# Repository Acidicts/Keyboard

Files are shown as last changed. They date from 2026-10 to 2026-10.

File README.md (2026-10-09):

# Keyboard
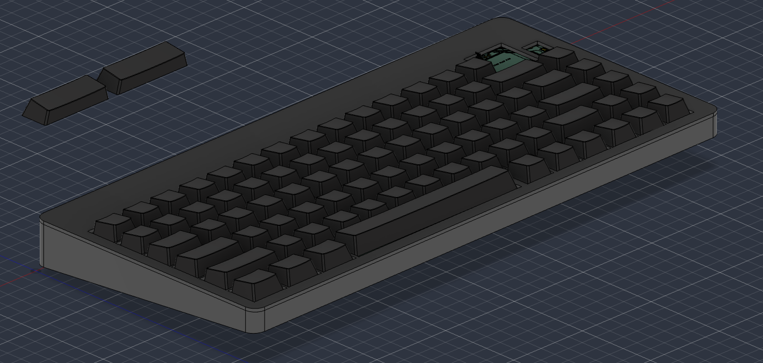
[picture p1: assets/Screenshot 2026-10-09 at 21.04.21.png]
assembly





Sooo, this is a keyboard with a fun little oled display (via i2c) and rotary encoder with some rgb leds, following a modified ansi layout: `"` and `@` are swapped

### Features
- Powered via usb-c
- Wired keyboard
- RP2354A (2MB on onboard memory)
- RGB LEDS

### Models
- [Keyboard Assemble  (f3z)](.Assembly.f3z)
- [Keyboard Case      (step)](./case/Case.step)
- [Keyboard Top Plate (step)](./case/Top-Plate.step)

### Assembly
- The case is a bit bigger than most 3d printers so you may need a 3rd party service for it
- Any ansi keycap set compatible with 75% keyboards should work i have not included price for them as you can make them in many ways,  either buy, 3d print, etc
- feel free to swap the `@` and `"` back if you prefer it that way just edit the [main.py](/firmware/main.py)
1. I recommend using PCBA for the top layer as those parts may be difficult to solder
2. On arrival of your half made pcb, start with soldering on the diodes facing in the direction of the silkscreen diagram
3. After solder on the rgb leds matching the notch up to the silkscreen too
4. Finally solder on your key switches to the board (I didn't want to give anyone the pain of manually soldering hot swaps on)
5. Put on your keycaps to key switches
6. Use a soldering iron to put in a m3 heat insert into the hole in the case
7. Put the pcb in the case
8. use a m3 screw to firmly mount to case but be wary of the underneath components so use spacers for it

### Case
[case](/case/Case.step)
[https://a360.co/476DL3y](https://a360.co/476DL3y)

### Firmware
1. Download the latest release of circuitpython from [here](https://downloads.circuitpython.org/bin/seeeduino_xiao_rp2040/en_GB/adafruit-circuitpython-seeeduino_xiao_rp2040-en_GB-10.3.0.uf2)
2. whilst powering the board (by plugging in usbc) hold down the boot button(labelled as `SW1` and plug it into your computer. The board should show up as a USB drive called `RPI-RP2` or something similar.
3. Drag and drop the downloaded UF2 file onto the `RPI-RP2` drive. The board will reboot and show up as a USB drive called `CIRCUITPY`.
4. drag and drop the contents of the [`firmware`](./firmware) folder onto the `CIRCUITPY` drive.
5. Restart the board and it should now be ready to use.

### BOMs
| Name | Link |
| --- | --- |
| Overview | [here](./BOM.csv) |
| LCSC List (included in addition parts) | [here](./BOMS/LCSC_BOM.csv) |
| PCBA Parts | [here](./BOMS/jlcpcb_pcb_BOM.csv) |

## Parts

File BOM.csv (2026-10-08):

Name | Source | Quantity | Cost | Link
Leobog key switches | Epomaker | 100(84 needed) | $26.99 | https://epomaker.com/products/leobog-reaper-switch-set
PCB | JLCPCB | 5(1 needed) | $29.50 | https://jlcpcb.com
PCBA | JLCPCB | 2(1 needed) | $44.62 | https://jlcpcb.com
PCB Shipping | JLCPCB | 1 | $40.00 | https://jlcpcb.com
NCP1117-3.3_SOT223 | Farnell UK | 1 | $1.11( shipping not included ) | https://uk.farnell.com/onsemi/ncp1117stat3g/ic-voltage-regulator/dp/1703381
LCSC parts list | LCSC | N/A | $17.46 | https://www.lcsc.com

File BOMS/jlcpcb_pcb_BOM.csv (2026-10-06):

\Designator | Per Board Qty | Order Qty | Description | MPN | LCSC Part # | Type | Supplier | Line Price (USD)
C1, C2 | 2 | 4 | 15pF 0603 50V C0G | CL10C150JB8NNNC | C1644 | Basic | JLCPCB | 0.0452
C3, C4, C5 | 3 | 6 | 4.7µF 0603 16V | CL10A475KO8NNNC | C19666 | Basic | JLCPCB | 0.1770
C6, C7 | 2 | 4 | 10µF 0805 25V | CL21A106KAYNNNE | C15850 | Basic | JLCPCB | 0.2604
C10, C11, C12, C13... |  | 24 | 100nF 0603 X7R | CC0603KRX7R9BB104 | C14663 | Basic | JLCPCB | 0.2952
L1 | 1 | 5 | 3.3µH inductor 2016 | AOTA-B201610S3R3-101-T | C42411119 | Extended | JLCPCB | 1.4145
R1, R2 | 2 | 20 | 5.1kΩ 0603 1% | FRC0603F5101TS | C2907044 | Extended | JLCPCB | 0.0440
R3, R5 | 2 | 20 | 27Ω 0805 5% | 0805W8F270JT5E | C17594 | Extended | JLCPCB | 0.0580
R4, R7, R8 | 3 | 20 | 1kΩ 0603 1% | RC0603FR-071KL | C22548 | Extended | JLCPCB | 0.0720
R9 | 1 | 20 | 33Ω 0603 1% | FRC0603F33R0TS | C2909394 | Extended | JLCPCB | 0.0540
SW1, SW2 | 2 | 6 | Push button switch 3x4x2.5mm | HX 3x4x2.5-PA-4N | C55200589 | Extended | JLCPCB | 0.1776
U1 | 1 | 2 | RP2354A microcontroller | RP2354A | C41378174 | Extended | JLCPCB | 2.5524
U2 | 1 | 5 | 12MHz crystal | ABM8-272-T3 | C20625731 | Extended | JLCPCB | 3.0970
USB1 | 1 | 3 | USB Type-C 16-pin connector | TYPE-C 16PIN 2MD(073) | C2765186 | Extended | JLCPCB | 0.2229

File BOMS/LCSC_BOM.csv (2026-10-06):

Name | Product ID | Quantity | Cost | Link
MBR0530 Diode | C5204746 | 90(84 needed) | $2.02 | https://www.lcsc.com/product-detail/C5204746.html
SK6812MINI-E | C5149201 | 90(84 needed) | $5.85 | https://www.lcsc.com/product-detail/C5149201.html
EC11E1834403 | C361165 | 1(1 needed) | $1.98 | https://www.lcsc.com/product-detail/C361165.html
Extra Costs(Shipping handling) | N/A | 1 | $7.61 | https://www.lcsc.com

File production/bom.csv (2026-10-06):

Designator | Footprint | Quantity | Value | LCSC Part #
C1, C2 | 0603 | 2 | 15pF
C10, C11, C12, C13, C14, C15, C16, C17, C18, C43, C8, C9 | 0603 | 12 | 100n
C19, C20, C21, C22, C23, C24, C25, C26, C27, C28, C29, C30, C31, C32, C33, C34, C35, C36, C37, C38, C39, C40, C41, C42, C6, C7 | 0805 | 26 | 10u
C3, C4, C5 | 0603 | 3 | 4.7u
D1, D10, D11, D12, D13, D14, D15, D16, D17, D18, D19, D2, D20, D21, D22, D23, D24, D25, D26, D27, D28, D29, D3, D30, D31, D32, D33, D34, D35, D36, D37, D38, D39, D4, D40, D41, D42, D43, D44, D45, D46, D47, D48, D49, D5, D50, D51, D52, D53, D54, D55, D56, D57, D58, D59, D6, D60, D61, D62, D63, D64, D65, D66, D67, D68, D69, D7, D70, D71, D72, D73, D74, D75, D76, D77, D78, D79, D8, D80, D81, D82, D9 | LED_SK6812MINI-E_3.2x2.8mm_P1.5mm_ReverseMount | 82 | SK6812MINI-E
J1 | SSD1306_OLED_0.96 | 1 | Conn_01x04_Pin
L1 | IND-SMD_L2.0-W1.6_AOTA-B201610S3R3-101-T | 1 | AOTA-B201610S3R3-101-T | C42411119
R1, R2 | R0603 | 2 | FRC0603F5101TS | C2907044
R3, R5 | R0805 | 2 | 0805W8F270JT5E | C17594
R4, R7, R8 | 0603 | 3 | RC0603FR-071KL | C22548
R9 | R0603 | 1 | FRC0603F33R0TS | C2909394
SW1, SW2 | SW-SMD_4P-L4.2-W3.4-P2.15-LS5.2 | 2 | HX 3X4X2.5-PA-4N PUSH BUTTON SWITCH | C55200589
SW10, SW11, SW12, SW13, SW14, SW15, SW17, SW18, SW19, SW20, SW21, SW22, SW23, SW24, SW25, SW26, SW27, SW28, SW29, SW3, SW30, SW32, SW34, SW35, SW36, SW37, SW38, SW39, SW4, SW40, SW41, SW42, SW43, SW44, SW45, SW47, SW49, SW5, SW50, SW51, SW52, SW53, SW54, SW55, SW56, SW57, SW58, SW59, SW6, SW62, SW64, SW65, SW66, SW67, SW68, SW69, SW7, SW70, SW71, SW72, SW73, SW75, SW77, SW8, SW87, SW88, SW89, SW9, SW90, SW91, SW92 | SW_Cherry_MX_1.00u_PCB | 71 | SW_Push
SW16 | RotaryEncoder_Alps_EC11E-Switch_Vertical_H20mm | 1 | RotaryEncoder_Switch
SW31, SW48, SW60 | SW_Cherry_MX_2.00u_PCB | 3 | SW_Push
SW33, SW46 | SW_Cherry_MX_1.50u_PCB | 2 | SW_Push
SW63 | SW_Cherry_MX_2.25u_PCB | 1 | SW_Push
SW74 | SW_Cherry_MX_1.75u_PCB | 1 | SW_Push
SW78 | SW_Cherry_MX_1.25u_PCB | 1 | SW_Push
SW79, SW80 | SW_Cherry_MX_1.25u_Plate | 2 | SW_Push
SW81 | SW_Cherry_MX_6.25u_PCB | 1 | SW_Push
U1 | QFN-60-1EP_7x7mm_P0.4mm_EP3.4x3.4mm | 1 | RP2354A
U10, U11, U12, U13, U14, U15, U16, U17, U19, U20, U21, U22, U23, U24, U25, U26, U27, U28, U29, U30, U31, U32, U33, U34, U35, U36, U37, U38, U39, U4, U40, U41, U42, U43, U44, U45, U46, U47, U48, U49, U5, U50, U51, U52, U53, U54, U55, U56, U57, U58, U59, U6, U60, U61, U62, U63, U64, U65, U66, U67, U68, U69, U7, U70, U71, U72, U73, U74, U75, U76, U78, U79, U8, U80, U81, U82, U88, U89, U9, U90, U91, U92, U93 | SOD-123_L2.7-W1.6-LS3.7-RD-1 | 83 | MBR0530_C5204746 | C5204746
U2 | CRYSTAL-SMD_4P-L3.2-W2.5-BL | 1 | ABM8-272-T3_C20625731 | C20625731
U3 | SOT-223-3_TabPin2 | 1 | NCP1117-3.3_SOT223
USB1 | USB-C-SMD_TYPE-C-16PIN-2MD-073 | 1 | TYPE-C 16PIN 2MD | C2765186

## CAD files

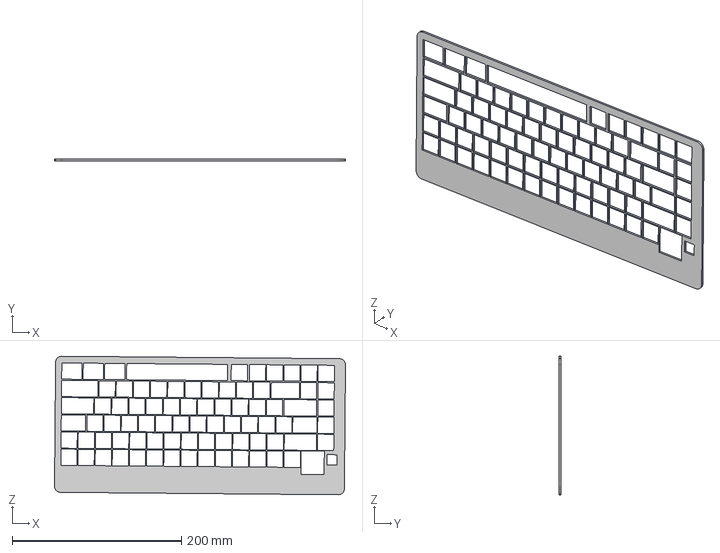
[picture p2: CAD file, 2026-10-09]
case/Top-Plate.step
344.3 x 2.00 x 163.9 mm

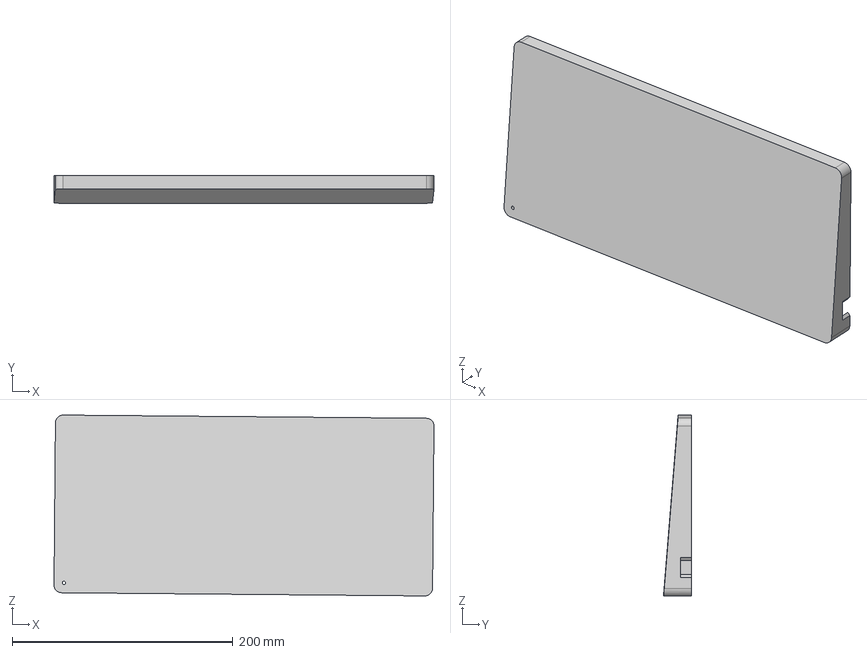
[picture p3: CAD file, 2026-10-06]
case/Case.step
344.3 x 25.0 x 163.9 mm

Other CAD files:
Assembly.f3z

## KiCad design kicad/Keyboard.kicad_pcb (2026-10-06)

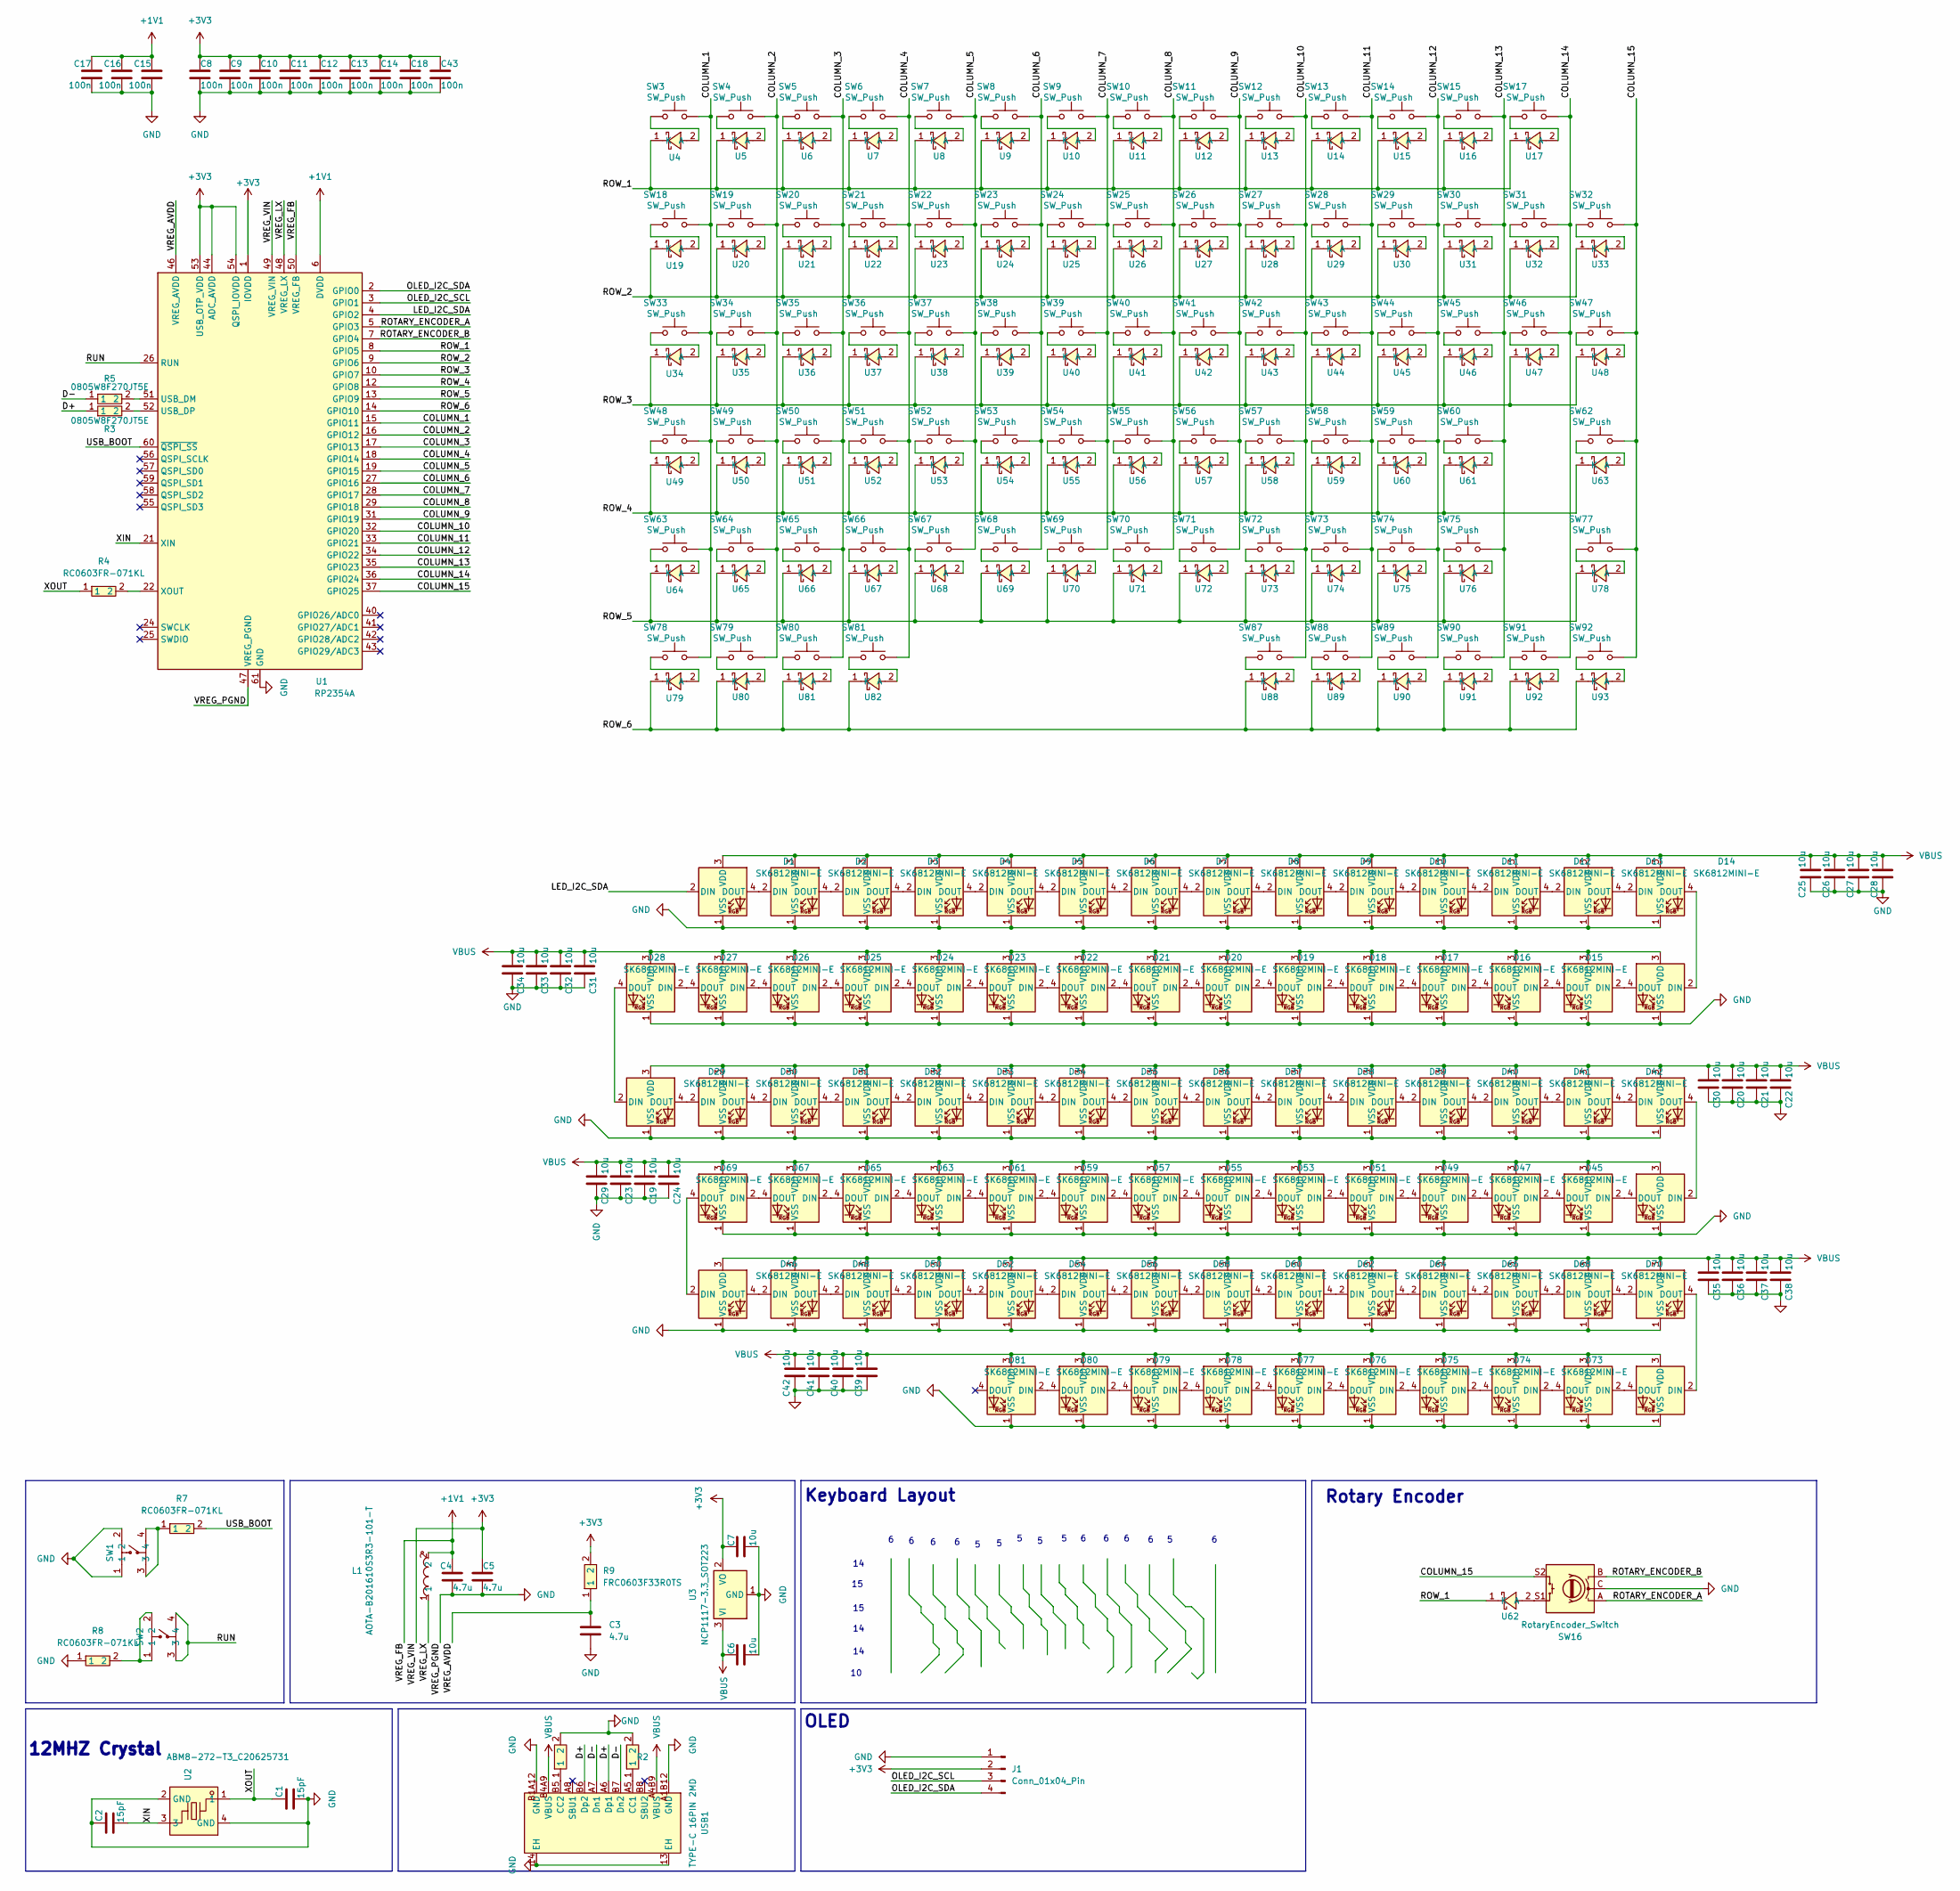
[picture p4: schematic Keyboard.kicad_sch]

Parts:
C1, C2: 15pF; C_0603_1608Metric
C3, C4, C5: 4.7u; C_0603_1608Metric
C6, C7, C19, C20, C21, C22, C23, C24, C25, C26, C27, C28, C29, C30, C31, C32, C33, C34, C35, C36, C37, C38, C39, C40, C41, C42: 10u; C_0805_2012Metric
C8, C9, C10, C11, C12, C13, C14, C15, C16, C17, C18, C43: 100n; C_0603_1608Metric
D1, D2, D3, D4, D5, D6, D7, D8, D9, D10, D11, D12, D13, D14, D15, D16, D17, D18, D19, D20, D21, D22, D23, D24, D25, D26, D27, D28, D29, D30, D31, D32, D33, D34, D35, D36, D37, D38, D39, D40, D41, D42, D43, D44, D45, D46, D47, D48, D49, D50, D51, D52, D53, D54, D55, D56, D57, D58, D59, D60, D61, D62, D63, D64, D65, D66, D67, D68, D69, D70, D71, D72, D73, D74, D75, D76, D77, D78, D79, D80, D81, D82: SK6812MINI-E; LED_SK6812MINI-E_3.2x2.8mm_P1.5mm_ReverseMount
J1: Conn_01x04_Pin; SSD1306_OLED_0.96
L1: AOTA-B201610S3R3-101-T; IND-SMD_L2.0-W1.6_AOTA-B201610S3R3-101-T; MPN AOTA-B201610S3R3-101-T; LCSC Part C42411119
R1, R2: FRC0603F5101TS; R0603; MPN FRC0603F5101TS; LCSC Part C2907044
R3, R5: 0805W8F270JT5E; R0805; MPN 0805W8F270JT5E; LCSC Part C17594
R4, R7, R8: RC0603FR-071KL; R_0603_1608Metric; MPN RC0603FR-071KL; LCSC Part C22548
R9: FRC0603F33R0TS; R0603; MPN FRC0603F33R0TS; LCSC Part C2909394
SW1, SW2: HX 3X4X2.5-PA-4N PUSH BUTTON SWITCH; SW-SMD_4P-L4.2-W3.4-P2.15-LS5.2; MPN HX 3x4x2.5-PA-4N push button switch; LCSC Part C55200589
SW3, SW4, SW5, SW6, SW7, SW8, SW9, SW10, SW11, SW12, SW13, SW14, SW15, SW17, SW18, SW19, SW20, SW21, SW22, SW23, SW24, SW25, SW26, SW27, SW28, SW29, SW30, SW32, SW34, SW35, SW36, SW37, SW38, SW39, SW40, SW41, SW42, SW43, SW44, SW45, SW47, SW49, SW50, SW51, SW52, SW53, SW54, SW55, SW56, SW57, SW58, SW59, SW62, SW64, SW65, SW66, SW67, SW68, SW69, SW70, SW71, SW72, SW73, SW75, SW77, SW87, SW88, SW89, SW90, SW91, SW92: SW_Push; SW_Cherry_MX_1.00u_PCB
SW16: RotaryEncoder_Switch; RotaryEncoder_Alps_EC11E-Switch_Vertical_H20mm
SW31, SW48, SW60: SW_Push; SW_Cherry_MX_2.00u_PCB
SW33, SW46: SW_Push; SW_Cherry_MX_1.50u_PCB
SW63: SW_Push; SW_Cherry_MX_2.25u_PCB
SW74: SW_Push; SW_Cherry_MX_1.75u_PCB
SW78: SW_Push; SW_Cherry_MX_1.25u_PCB
SW79, SW80: SW_Push; SW_Cherry_MX_1.25u_Plate
SW81: SW_Push; SW_Cherry_MX_6.25u_PCB
U1: RP2354A; QFN-60-1EP_7x7mm_P0.4mm_EP3.4x3.4mm
U2: ABM8-272-T3_C20625731; CRYSTAL-SMD_4P-L3.2-W2.5-BL; MPN ABM8-272-T3; LCSC Part C20625731
U3: NCP1117-3.3_SOT223; SOT-223-3_TabPin2
U4, U5, U6, U7, U8, U9, U10, U11, U12, U13, U14, U15, U16, U17, U19, U20, U21, U22, U23, U24, U25, U26, U27, U28, U29, U30, U31, U32, U33, U34, U35, U36, U37, U38, U39, U40, U41, U42, U43, U44, U45, U46, U47, U48, U49, U50, U51, U52, U53, U54, U55, U56, U57, U58, U59, U60, U61, U62, U63, U64, U65, U66, U67, U68, U69, U70, U71, U72, U73, U74, U75, U76, U78, U79, U80, U81, U82, U88, U89, U90, U91, U92, U93: MBR0530_C5204746; SOD-123_L2.7-W1.6-LS3.7-RD-1; MPN MBR0530; LCSC Part C5204746
USB1: TYPE-C 16PIN 2MD; USB-C-SMD_TYPE-C-16PIN-2MD-073; MPN TYPE-C 16PIN 2MD(073); LCSC Part C2765186

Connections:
+1V1: C4.1, C15.1, C16.1, C17.1, L1.2, U1.6 (DVDD), U1.23 (DVDD), U1.39 (DVDD), U1.50 (VREG_FB)
+3V3: C5.1, C7.1, C8.1, C9.1, C10.1, C11.1, C12.1, C13.1, C14.1, C18.1, C43.1, J1.2, R9.2, U1.1 (IOVDD), U1.11 (IOVDD), U1.20 (IOVDD), U1.30 (IOVDD), U1.38 (IOVDD), U1.44 (ADC_AVDD), U1.45 (IOVDD), U1.49 (VREG_VIN), U1.53 (USB_OTP_VDD), U1.54 (QSPI_IOVDD), U3.2 (VO)
/COLUMN_1: SW3.2, SW18.2, SW33.2, SW48.2, SW63.2, SW78.2, U1.15 (GPIO11)
/COLUMN_2: SW4.2, SW19.2, SW34.2, SW49.2, SW64.2, SW79.2, U1.16 (GPIO12)
/COLUMN_3: SW5.2, SW20.2, SW35.2, SW50.2, SW65.2, SW80.2, U1.17 (GPIO13)
/COLUMN_4: SW6.2, SW21.2, SW36.2, SW51.2, SW66.2, SW81.2, U1.18 (GPIO14)
/COLUMN_5: SW7.2, SW22.2, SW37.2, SW52.2, SW67.2, U1.19 (GPIO15)
/COLUMN_6: SW8.2, SW23.2, SW38.2, SW53.2, SW68.2, U1.27 (GPIO16)
/COLUMN_7: SW9.2, SW24.2, SW39.2, SW54.2, SW69.2, U1.28 (GPIO17)
/COLUMN_8: SW10.2, SW25.2, SW40.2, SW55.2, SW70.2, U1.29 (GPIO18)
/COLUMN_9: SW11.2, SW26.2, SW41.2, SW56.2, SW71.2, U1.31 (GPIO19)
/COLUMN_10: SW12.2, SW27.2, SW42.2, SW57.2, SW72.2, SW87.2, U1.32 (GPIO20)
/COLUMN_11: SW13.2, SW28.2, SW43.2, SW58.2, SW73.2, SW88.2, U1.33 (GPIO21)
/COLUMN_12: SW14.2, SW29.2, SW44.2, SW59.2, SW74.2, SW89.2, U1.34 (GPIO22)
/COLUMN_13: SW15.2, SW30.2, SW45.2, SW60.2, SW75.2, SW90.2, U1.35 (GPIO23)
/COLUMN_14: SW17.2, SW31.2, SW46.2, SW91.2, U1.36 (GPIO24)
/COLUMN_15: SW16.S2, SW32.2, SW47.2, SW62.2, SW77.2, SW92.2, U1.37 (GPIO25)
/D+: R3.1, USB1.A6 (Dp1), USB1.B6 (Dp2)
/D-: R5.1, USB1.A7 (Dn1), USB1.B7 (Dn2)
/LED_I2C_SDA: D1.2 (DIN), U1.4 (GPIO2)
/OLED_I2C_SCL: J1.3, U1.3 (GPIO1)
/OLED_I2C_SDA: J1.4, U1.2 (GPIO0)
/ROTARY_ENCODER_A: SW16.A, U1.5 (GPIO3)
/ROTARY_ENCODER_B: SW16.B, U1.7 (GPIO4)
/ROW_1: U1.8 (GPIO5), U4.1 (K), U5.1 (K), U6.1 (K), U7.1 (K), U8.1 (K), U9.1 (K), U10.1 (K), U11.1 (K), U12.1 (K), U13.1 (K), U14.1 (K), U15.1 (K), U16.1 (K), U17.1 (K), U62.1 (K)
/ROW_2: U1.9 (GPIO6), U19.1 (K), U20.1 (K), U21.1 (K), U22.1 (K), U23.1 (K), U24.1 (K), U25.1 (K), U26.1 (K), U27.1 (K), U28.1 (K), U29.1 (K), U30.1 (K), U31.1 (K), U32.1 (K), U33.1 (K)
/ROW_3: U1.10 (GPIO7), U34.1 (K), U35.1 (K), U36.1 (K), U37.1 (K), U38.1 (K), U39.1 (K), U40.1 (K), U41.1 (K), U42.1 (K), U43.1 (K), U44.1 (K), U45.1 (K), U46.1 (K), U47.1 (K), U48.1 (K)
/ROW_4: U1.12 (GPIO8), U49.1 (K), U50.1 (K), U51.1 (K), U52.1 (K), U53.1 (K), U54.1 (K), U55.1 (K), U56.1 (K), U57.1 (K), U58.1 (K), U59.1 (K), U60.1 (K), U61.1 (K), U63.1 (K)
/ROW_5: U1.13 (GPIO9), U64.1 (K), U65.1 (K), U66.1 (K), U67.1 (K), U68.1 (K), U69.1 (K), U70.1 (K), U71.1 (K), U72.1 (K), U73.1 (K), U74.1 (K), U75.1 (K), U76.1 (K), U78.1 (K)
/ROW_6: U1.14 (GPIO10), U79.1 (K), U80.1 (K), U81.1 (K), U82.1 (K), U88.1 (K), U89.1 (K), U90.1 (K), U91.1 (K), U92.1 (K), U93.1 (K)
/RUN: SW2.3, SW2.4, U1.26 (RUN)
/USB_BOOT: R7.2, U1.60 (~QSPI_SS)
/VREG_AVDD: C3.1, R9.1, U1.46 (VREG_AVDD)
/VREG_LX: L1.1, U1.48 (VREG_LX)
/XIN: C2.2, U1.21 (XIN), U2.3
/XOUT: C1.1, R4.1, U2.1
GND: C1.2, C2.1, C3.2, C4.2, C5.2, C6.2, C7.2, C8.2, C9.2, C10.2, C11.2, C12.2, C13.2, C14.2, C15.2, C16.2, C17.2, C18.2, C19.1, C20.1, C21.1, C22.1, C23.1, C24.1, C25.1, C26.1, C27.1, C28.1, C29.1, C30.1, C31.1, C32.1, C33.1, C34.1, C35.1, C36.1, C37.1, C38.1, C39.1, C40.1, C41.1, C42.1, C43.2, D1.1 (VSS), D2.1 (VSS), D3.1 (VSS), D4.1 (VSS), D5.1 (VSS), D6.1 (VSS), D7.1 (VSS), D8.1 (VSS), D9.1 (VSS), D10.1 (VSS), D11.1 (VSS), D12.1 (VSS), D13.1 (VSS), D14.1 (VSS), D15.1 (VSS), D16.1 (VSS), D17.1 (VSS), D18.1 (VSS), D19.1 (VSS), D20.1 (VSS), D21.1 (VSS), D22.1 (VSS), D23.1 (VSS), D24.1 (VSS), D25.1 (VSS), D26.1 (VSS), D27.1 (VSS), D28.1 (VSS), D29.1 (VSS), D30.1 (VSS), D31.1 (VSS), D32.1 (VSS), D33.1 (VSS), D34.1 (VSS), D35.1 (VSS), D36.1 (VSS), D37.1 (VSS), D38.1 (VSS), D39.1 (VSS), D40.1 (VSS), D41.1 (VSS), D42.1 (VSS), D43.1 (VSS), D44.1 (VSS), D45.1 (VSS), D46.1 (VSS), D47.1 (VSS), D48.1 (VSS), D49.1 (VSS), D50.1 (VSS), D51.1 (VSS), D52.1 (VSS), D53.1 (VSS), D54.1 (VSS), D55.1 (VSS), D56.1 (VSS), D57.1 (VSS), D58.1 (VSS), D59.1 (VSS), D60.1 (VSS), D61.1 (VSS), D62.1 (VSS), D63.1 (VSS), D64.1 (VSS), D65.1 (VSS), D66.1 (VSS), D67.1 (VSS), D68.1 (VSS), D69.1 (VSS), D70.1 (VSS), D71.1 (VSS), D72.1 (VSS), D73.1 (VSS), D74.1 (VSS), D75.1 (VSS), D76.1 (VSS), D77.1 (VSS), D78.1 (VSS), D79.1 (VSS), D80.1 (VSS), D81.1 (VSS), D82.1 (VSS), J1.1, R1.2, R2.2, R8.1, SW1.1, SW1.2, SW16.C, U1.47 (VREG_PGND), U1.61 (GND), U2.2 (GND), U2.4 (GND), U3.1 (GND), USB1.13 (EH), USB1.14 (EH), USB1.A1B12 (GND), USB1.B1A12 (GND)
unnamed: D1.4 (DOUT), D2.2 (DIN)
unnamed: D2.4 (DOUT), D3.2 (DIN)
unnamed: D3.4 (DOUT), D4.2 (DIN)
unnamed: D4.4 (DOUT), D5.2 (DIN)
unnamed: D5.4 (DOUT), D6.2 (DIN)
unnamed: D6.4 (DOUT), D7.2 (DIN)
unnamed: D7.4 (DOUT), D8.2 (DIN)
unnamed: D8.4 (DOUT), D9.2 (DIN)
unnamed: D9.4 (DOUT), D10.2 (DIN)
unnamed: D10.4 (DOUT), D11.2 (DIN)
unnamed: D11.4 (DOUT), D12.2 (DIN)
unnamed: D12.4 (DOUT), D13.2 (DIN)
unnamed: D13.4 (DOUT), D14.2 (DIN)
unnamed: D14.4 (DOUT), D15.2 (DIN)
unnamed: D15.4 (DOUT), D16.2 (DIN)
unnamed: D16.4 (DOUT), D17.2 (DIN)
unnamed: D17.4 (DOUT), D18.2 (DIN)
unnamed: D18.4 (DOUT), D19.2 (DIN)
unnamed: D19.4 (DOUT), D20.2 (DIN)
unnamed: D20.4 (DOUT), D21.2 (DIN)
unnamed: D21.4 (DOUT), D22.2 (DIN)
unnamed: D22.4 (DOUT), D23.2 (DIN)
unnamed: D23.4 (DOUT), D24.2 (DIN)
unnamed: D24.4 (DOUT), D25.2 (DIN)
unnamed: D25.4 (DOUT), D26.2 (DIN)
unnamed: D26.4 (DOUT), D27.2 (DIN)
unnamed: D27.4 (DOUT), D28.2 (DIN)
unnamed: D28.4 (DOUT), D43.2 (DIN)
unnamed: D29.2 (DIN), D43.4 (DOUT)
unnamed: D29.4 (DOUT), D30.2 (DIN)
unnamed: D30.4 (DOUT), D31.2 (DIN)
unnamed: D31.4 (DOUT), D32.2 (DIN)
unnamed: D32.4 (DOUT), D33.2 (DIN)
unnamed: D33.4 (DOUT), D34.2 (DIN)
unnamed: D34.4 (DOUT), D35.2 (DIN)
unnamed: D35.4 (DOUT), D36.2 (DIN)
unnamed: D36.4 (DOUT), D37.2 (DIN)
unnamed: D37.4 (DOUT), D38.2 (DIN)
unnamed: D38.4 (DOUT), D39.2 (DIN)
unnamed: D39.4 (DOUT), D40.2 (DIN)
unnamed: D40.4 (DOUT), D41.2 (DIN)
unnamed: D41.4 (DOUT), D42.2 (DIN)
unnamed: D42.4 (DOUT), D44.2 (DIN)
unnamed: D44.4 (DOUT), D45.2 (DIN)
unnamed: D45.4 (DOUT), D47.2 (DIN)
unnamed: D46.2 (DIN), D71.4 (DOUT)
unnamed: D46.4 (DOUT), D48.2 (DIN)
unnamed: D47.4 (DOUT), D49.2 (DIN)
unnamed: D48.4 (DOUT), D50.2 (DIN)
unnamed: D49.4 (DOUT), D51.2 (DIN)
unnamed: D50.4 (DOUT), D52.2 (DIN)
unnamed: D51.4 (DOUT), D53.2 (DIN)
unnamed: D52.4 (DOUT), D54.2 (DIN)
unnamed: D53.4 (DOUT), D55.2 (DIN)
unnamed: D54.4 (DOUT), D56.2 (DIN)
unnamed: D55.4 (DOUT), D57.2 (DIN)
unnamed: D56.4 (DOUT), D58.2 (DIN)
unnamed: D57.4 (DOUT), D59.2 (DIN)
unnamed: D58.4 (DOUT), D60.2 (DIN)
unnamed: D59.4 (DOUT), D61.2 (DIN)
unnamed: D60.4 (DOUT), D62.2 (DIN)
unnamed: D61.4 (DOUT), D63.2 (DIN)
unnamed: D62.4 (DOUT), D64.2 (DIN)
unnamed: D63.4 (DOUT), D65.2 (DIN)
unnamed: D64.4 (DOUT), D66.2 (DIN)
unnamed: D65.4 (DOUT), D67.2 (DIN)
unnamed: D66.4 (DOUT), D68.2 (DIN)
unnamed: D67.4 (DOUT), D69.2 (DIN)
unnamed: D68.4 (DOUT), D70.2 (DIN)
unnamed: D69.4 (DOUT), D71.2 (DIN)
unnamed: D70.4 (DOUT), D72.2 (DIN)
unnamed: D72.4 (DOUT), D73.2 (DIN)
unnamed: D73.4 (DOUT), D74.2 (DIN)
unnamed: D74.4 (DOUT), D75.2 (DIN)
unnamed: D75.4 (DOUT), D76.2 (DIN)
unnamed: D76.4 (DOUT), D77.2 (DIN)
unnamed: D77.4 (DOUT), D78.2 (DIN)
unnamed: D78.4 (DOUT), D79.2 (DIN)
unnamed: D79.4 (DOUT), D80.2 (DIN)
unnamed: D80.4 (DOUT), D81.2 (DIN)
unnamed: D81.4 (DOUT), D82.2 (DIN)
unnamed: R7.1, SW1.3, SW1.4
unnamed: R8.2, SW2.1, SW2.2
unnamed: R5.2, U1.51 (USB_DM)
unnamed: R3.2, U1.52 (USB_DP)
unnamed: R4.2, U1.22 (XOUT)
unnamed: SW3.1, U4.2 (A)
unnamed: SW4.1, U5.2 (A)
unnamed: SW5.1, U6.2 (A)
unnamed: SW6.1, U7.2 (A)
unnamed: SW7.1, U8.2 (A)
unnamed: SW8.1, U9.2 (A)
unnamed: SW9.1, U10.2 (A)
unnamed: SW10.1, U11.2 (A)
unnamed: SW11.1, U12.2 (A)
unnamed: SW12.1, U13.2 (A)
unnamed: SW13.1, U14.2 (A)
unnamed: SW14.1, U15.2 (A)
unnamed: SW15.1, U16.2 (A)
unnamed: SW17.1, U17.2 (A)
unnamed: SW18.1, U19.2 (A)
unnamed: SW19.1, U20.2 (A)
unnamed: SW20.1, U21.2 (A)
unnamed: SW21.1, U22.2 (A)
unnamed: SW22.1, U23.2 (A)
unnamed: SW23.1, U24.2 (A)
unnamed: SW24.1, U25.2 (A)
unnamed: SW25.1, U26.2 (A)
unnamed: SW26.1, U27.2 (A)
unnamed: SW27.1, U28.2 (A)
unnamed: SW28.1, U29.2 (A)
unnamed: SW29.1, U30.2 (A)
unnamed: SW30.1, U31.2 (A)
unnamed: SW31.1, U32.2 (A)
unnamed: SW32.1, U33.2 (A)
unnamed: SW33.1, U34.2 (A)
unnamed: SW34.1, U35.2 (A)
unnamed: SW35.1, U36.2 (A)
unnamed: SW36.1, U37.2 (A)
unnamed: SW37.1, U38.2 (A)
unnamed: SW38.1, U39.2 (A)
unnamed: SW39.1, U40.2 (A)
unnamed: SW40.1, U41.2 (A)
unnamed: SW41.1, U42.2 (A)
unnamed: SW42.1, U43.2 (A)
unnamed: SW43.1, U44.2 (A)
unnamed: SW44.1, U45.2 (A)
unnamed: SW45.1, U46.2 (A)
unnamed: SW46.1, U47.2 (A)
unnamed: SW47.1, U48.2 (A)
unnamed: SW48.1, U49.2 (A)
unnamed: SW49.1, U50.2 (A)
unnamed: SW50.1, U51.2 (A)
unnamed: SW51.1, U52.2 (A)
unnamed: SW52.1, U53.2 (A)
unnamed: SW53.1, U54.2 (A)
unnamed: SW54.1, U55.2 (A)
unnamed: SW55.1, U56.2 (A)
unnamed: SW56.1, U57.2 (A)
unnamed: SW57.1, U58.2 (A)
unnamed: SW58.1, U59.2 (A)
unnamed: SW59.1, U60.2 (A)
unnamed: SW60.1, U61.2 (A)
unnamed: SW16.S1, U62.2 (A)
unnamed: SW62.1, U63.2 (A)
unnamed: SW63.1, U64.2 (A)
unnamed: SW64.1, U65.2 (A)
unnamed: SW65.1, U66.2 (A)
unnamed: SW66.1, U67.2 (A)
unnamed: SW67.1, U68.2 (A)
unnamed: SW68.1, U69.2 (A)
unnamed: SW69.1, U70.2 (A)
unnamed: SW70.1, U71.2 (A)
unnamed: SW71.1, U72.2 (A)
unnamed: SW72.1, U73.2 (A)
unnamed: SW73.1, U74.2 (A)
unnamed: SW74.1, U75.2 (A)
unnamed: SW75.1, U76.2 (A)
unnamed: SW77.1, U78.2 (A)
unnamed: SW78.1, U79.2 (A)
unnamed: SW79.1, U80.2 (A)
unnamed: SW80.1, U81.2 (A)
unnamed: SW81.1, U82.2 (A)
unnamed: SW87.1, U88.2 (A)
unnamed: SW88.1, U89.2 (A)
unnamed: SW89.1, U90.2 (A)
unnamed: SW90.1, U91.2 (A)
unnamed: SW91.1, U92.2 (A)
unnamed: SW92.1, U93.2 (A)
unnamed: R2.1, USB1.A5 (CC1)
unnamed: R1.1, USB1.B5 (CC2)
VBUS: C6.1, C19.2, C20.2, C21.2, C22.2, C23.2, C24.2, C25.2, C26.2, C27.2, C28.2, C29.2, C30.2, C31.2, C32.2, C33.2, C34.2, C35.2, C36.2, C37.2, C38.2, C39.2, C40.2, C41.2, C42.2, D1.3 (VDD), D2.3 (VDD), D3.3 (VDD), D4.3 (VDD), D5.3 (VDD), D6.3 (VDD), D7.3 (VDD), D8.3 (VDD), D9.3 (VDD), D10.3 (VDD), D11.3 (VDD), D12.3 (VDD), D13.3 (VDD), D14.3 (VDD), D15.3 (VDD), D16.3 (VDD), D17.3 (VDD), D18.3 (VDD), D19.3 (VDD), D20.3 (VDD), D21.3 (VDD), D22.3 (VDD), D23.3 (VDD), D24.3 (VDD), D25.3 (VDD), D26.3 (VDD), D27.3 (VDD), D28.3 (VDD), D29.3 (VDD), D30.3 (VDD), D31.3 (VDD), D32.3 (VDD), D33.3 (VDD), D34.3 (VDD), D35.3 (VDD), D36.3 (VDD), D37.3 (VDD), D38.3 (VDD), D39.3 (VDD), D40.3 (VDD), D41.3 (VDD), D42.3 (VDD), D43.3 (VDD), D44.3 (VDD), D45.3 (VDD), D46.3 (VDD), D47.3 (VDD), D48.3 (VDD), D49.3 (VDD), D50.3 (VDD), D51.3 (VDD), D52.3 (VDD), D53.3 (VDD), D54.3 (VDD), D55.3 (VDD), D56.3 (VDD), D57.3 (VDD), D58.3 (VDD), D59.3 (VDD), D60.3 (VDD), D61.3 (VDD), D62.3 (VDD), D63.3 (VDD), D64.3 (VDD), D65.3 (VDD), D66.3 (VDD), D67.3 (VDD), D68.3 (VDD), D69.3 (VDD), D70.3 (VDD), D71.3 (VDD), D72.3 (VDD), D73.3 (VDD), D74.3 (VDD), D75.3 (VDD), D76.3 (VDD), D77.3 (VDD), D78.3 (VDD), D79.3 (VDD), D80.3 (VDD), D81.3 (VDD), D82.3 (VDD), U3.3 (VI), USB1.A4B9 (VBUS), USB1.B4A9 (VBUS)

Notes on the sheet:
OLED
12MHZ Crystal
Keyboard Layout
Rotary Encoder

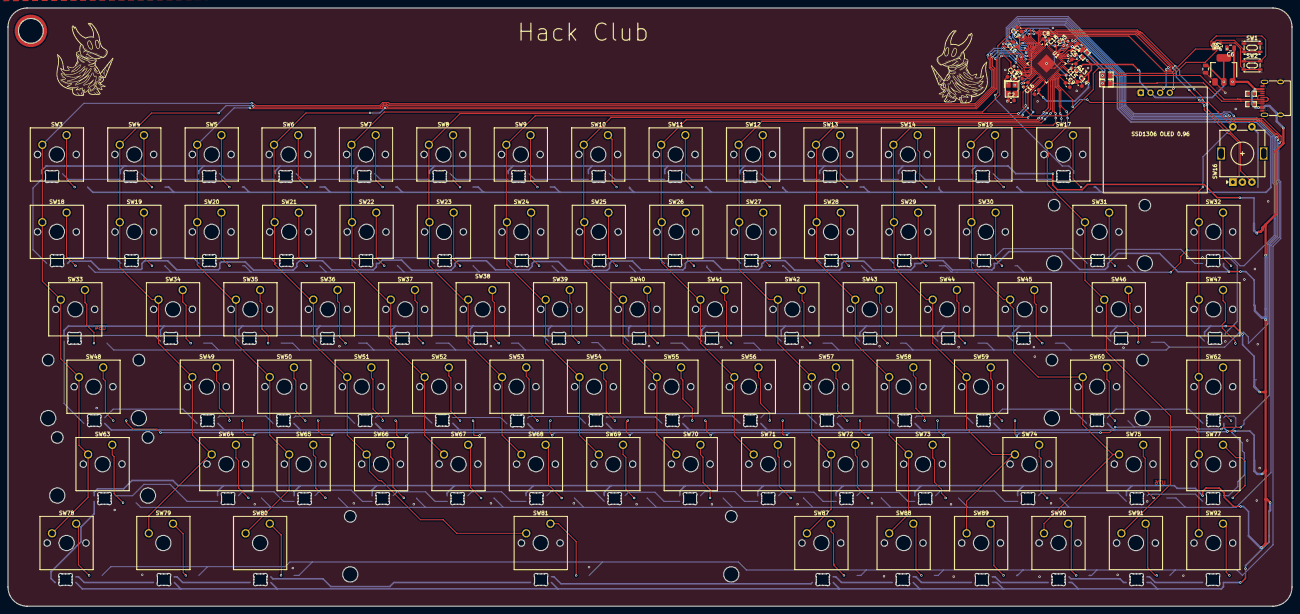
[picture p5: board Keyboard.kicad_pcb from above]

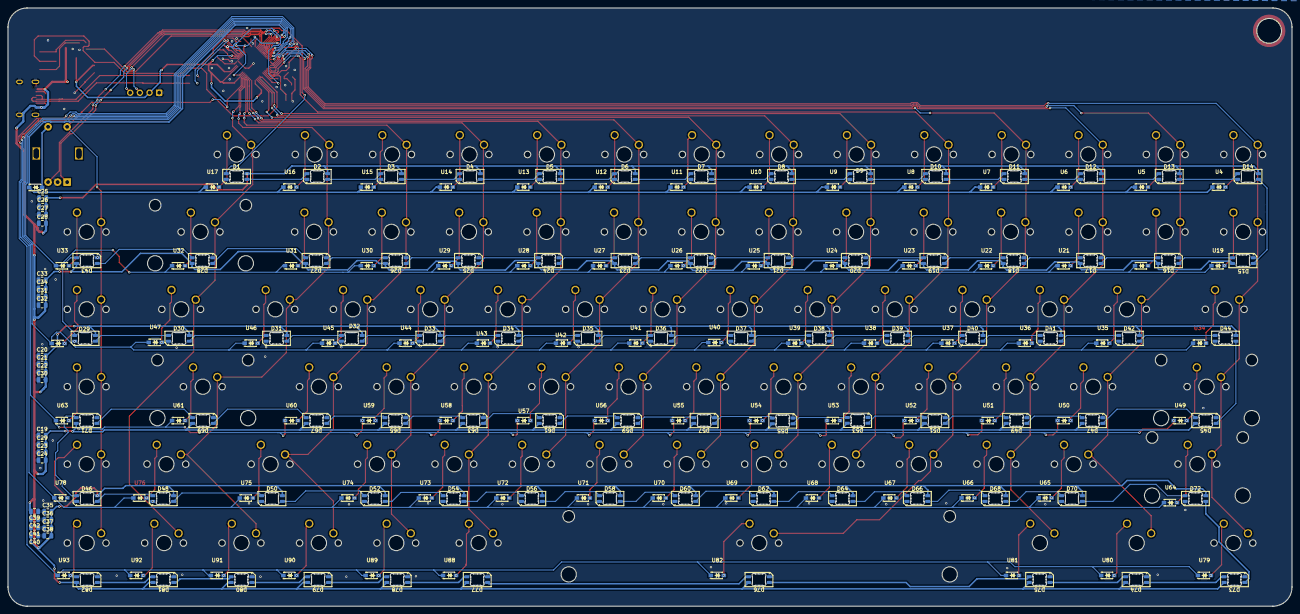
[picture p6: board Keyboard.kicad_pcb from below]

Board: 2 copper layers, 337.0 x 157.0 mm, 307 parts (189 on the bottom side), 209 nets.

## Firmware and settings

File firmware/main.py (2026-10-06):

import board
import busio

from kmk.kmkkeyboard import KMKKeyboard
from kmk.keys import KC
from kmk.scanners import DiodeOrientation
from kmk.modules.layers import Layers
from kmk.modules.encoder import EncoderHandler
from kmk.extensions.display import Display, TextEntry
from kmk.extensions.display.ssd1306 import SSD1306
from kmk.extensions.RGB import RGB, AnimationModes

NUM_LEDS = 84

COL_PINS = {
    0:  "GP11",
    1:  "GP12",
    2:  "GP13",
    3:  "GP14",
    4:  "GP15",
    5:  "GP16",
    6:  "GP17",
    7:  "GP18",
    8:  "GP19",
    9:  "GP20",
    10: "GP21",
    11: "GP22",
    12: "GP23",
    13: "GP24",
    14: "GP25",
}

ROW_PINS = {
    0: "GP5",
    1: "GP6",
    2: "GP7",
    3: "GP8",
    4: "GP9",
    5: "GP10",
}

missing = [f"col {k}" for k, v in COL_PINS.items() if not v] + \
          [f"row {k}" for k, v in ROW_PINS.items() if not v]
if missing:
    raise ValueError("Fill in these pins in code.py: " + ", ".join(missing))

keyboard = KMKKeyboard()

keyboard.col_pins = tuple(getattr(board, COL_PINS[i]) for i in range(len(COL_PINS)))
keyboard.row_pins = tuple(getattr(board, ROW_PINS[i]) for i in range(len(ROW_PINS)))

keyboard.diode_orientation = DiodeOrientation.COL2ROW

keyboard.modules.append(Layers())

encoder_handler = EncoderHandler()
keyboard.modules.append(encoder_handler)
encoder_handler.pins = ((board.GP3, board.GP4, None, False),)
encoder_handler.map = [
    ((KC.VOLD, KC.VOLU, None),),
    ((KC.BRID, KC.BRIU, None),),
]

i2c_bus = busio.I2C(board.GP1, board.GP0)
driver = SSD1306(i2c=i2c_bus, device_address=0x3C)
display = Display(
    display=driver,
    width=128,
    height=32,
    flip=False,
    brightness=0.8,
    dim_time=20,
    dim_target=0.1,
    off_time=60,
)
display.entries = [
    TextEntry(text='Layer:', x=0, y=0),
    TextEntry(text='BASE', x=48, y=0, layer=0),
    TextEntry(text='FN', x=48, y=0, layer=1),
]
keyboard.extensions.append(display)

rgb = RGB(
    pixel_pin=board.GP2,
    num_pixels=NUM_LEDS,
    rgb_order=(1, 0, 2),
    val_limit=100,
    hue_default=0,
    sat_default=100,
    val_default=60,
    animation_mode=AnimationModes.RAINBOW,
    animation_speed=1,
)
keyboard.extensions.append(rgb)

XXXXXXX = KC.NO
_______ = KC.TRNS

keyboard.keymap = [
    [
        [KC.ESC,  KC.F1,  KC.F2,  KC.F3,  KC.F4,  KC.F5,  KC.F6,  KC.F7,  KC.F8,  KC.F9,  KC.F10, KC.F11, KC.F12, KC.DEL,  KC.MUTE],
        [KC.GRV,  KC.N1,  KC.N2,  KC.N3,  KC.N4,  KC.N5,  KC.N6,  KC.N7,  KC.N8,  KC.N9,  KC.N0,  KC.MINS,KC.EQL, KC.BSPC, KC.PGUP],
        [KC.TAB,  KC.Q,   KC.W,   KC.E,   KC.R,   KC.T,   KC.Y,   KC.U,   KC.I,   KC.O,   KC.P,   KC.LBRC,KC.RBRC,KC.BSLS, KC.PGDN],
        [KC.CAPS, KC.A,   KC.S,   KC.D,   KC.F,   KC.G,   KC.H,   KC.J,   KC.K,   KC.L,   KC.SCLN,KC.QUOT,KC.ENT, XXXXXXX, KC.HOME],
        [KC.LSFT, KC.Z,   KC.X,   KC.C,   KC.V,   KC.B,   KC.N,   KC.M,   KC.COMM,KC.DOT, KC.SLSH,KC.RSFT,KC.UP,  XXXXXXX, KC.END],
        [KC.LCTL, KC.LALT,KC.LGUI,KC.SPC, XXXXXXX,XXXXXXX,XXXXXXX,XXXXXXX,XXXXXXX,KC.RGUI,KC.MO(1),KC.RCTL,KC.LEFT,KC.DOWN, KC.RIGHT],
    ],
    [[_______ for _ in range(15)] for _ in range(6)],
]

if __name__ == '__main__':
    keyboard.go()

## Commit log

2026-10-06 Enhance README with assembly and firmware details
    Added detailed instructions on assembly and firmware setup for the keyboard project, including features and images.
2026-10-08 Update BOM links in README.md
2026-10-09 added more files
    [Assembly.f3z, Top-Plate.step]
